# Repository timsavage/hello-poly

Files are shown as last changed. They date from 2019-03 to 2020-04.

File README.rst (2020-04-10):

############################################
Hello Poly - Polyphonic MIDI to CV interface
############################################

Polyphonic MIDI to CV module for modular synths, hardware designed for Eurorack systems.

Features:

- 6x 12bit DACs with a range of 0-~8.192V (assignable as either Note or Control outputs)
- 4x Gate outputs
- Configurable CV range 1V/Octave or 1.2V/Octave (providing a 100mV/step)
- Fully assignable routing of MIDI messages by channel
- Assignable Pitchbend and Channel Aftertouch
- Multiple Polyphony modes
- Support for multiple programs (controlled via program change events)
- Configuration via MIDI
- Gate controlled LFO.
- Firmware is hardware agnostic, could be compiled for other targets.

Hardware
========

- Designed around an STM32F411 32bit ARM MCU
- MSP4822 12bit DACs
- 128x64 SSD1306 OLED display

Software
========

Software currently using Arduino, however, I am migrating to using CMSIS and the STM32 HAL 
using the STM32CubeIDE mainly for the debugging support!

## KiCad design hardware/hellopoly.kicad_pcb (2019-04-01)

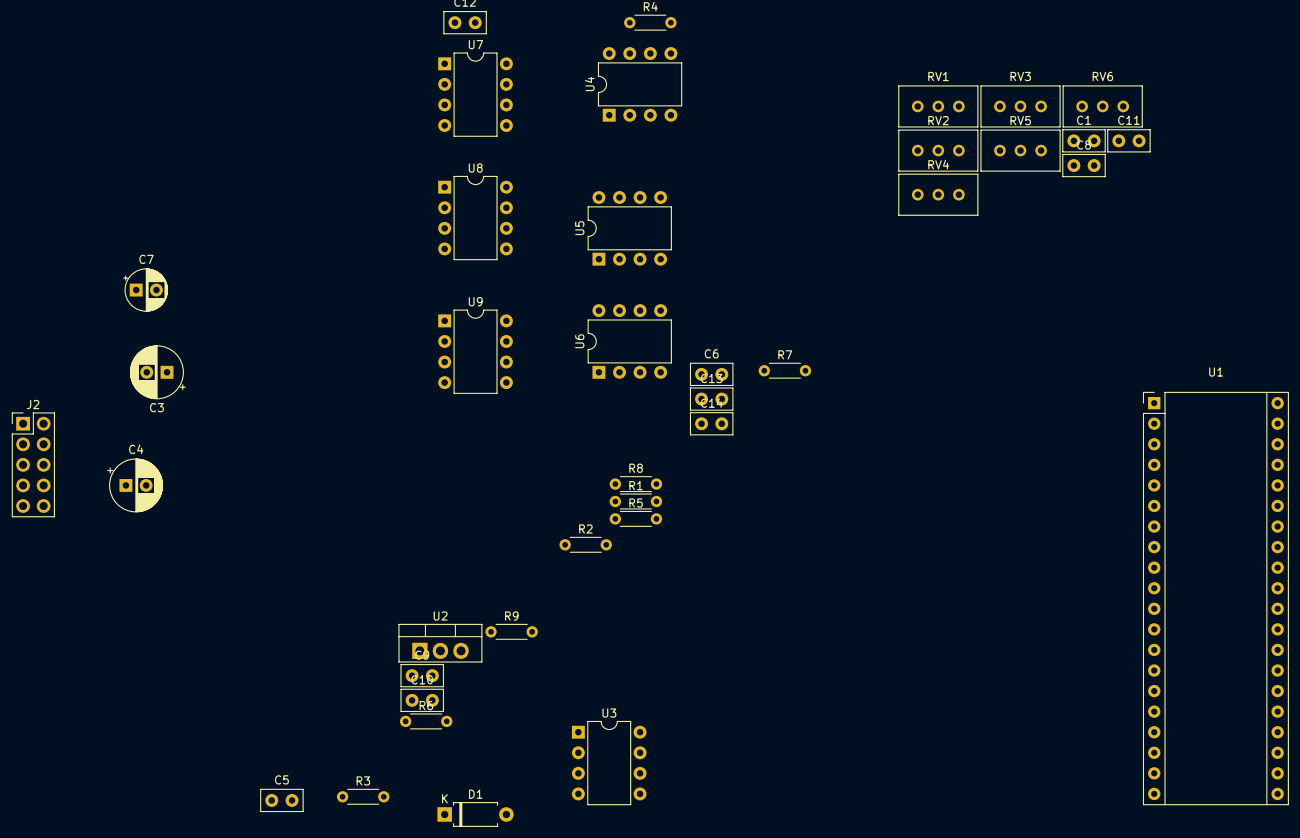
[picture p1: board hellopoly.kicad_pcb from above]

Board: 2 copper layers, 39 parts (0 on the bottom side), 38 nets, no tracks yet.

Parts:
C1, C5, C6, C8, C9, C10, C11, C12, C13, C14: 0.1uF; C_Disc_D5.0mm_W2.5mm_P2.50mm
C3, C4: 47u; CP_Radial_D6.3mm_P2.50mm
C7: 47uF; CP_Radial_D5.0mm_P2.50mm
D1: 1N4148; D_A-405_P7.62mm_Horizontal
J2: Power BUS; PinHeader_2x05_P2.54mm_Vertical
R1: 220R; R_Axial_DIN0204_L3.6mm_D1.6mm_P5.08mm_Horizontal
R2, R4, R5, R6, R7, R8, R9: 10K; R_Axial_DIN0204_L3.6mm_D1.6mm_P5.08mm_Horizontal
R3: 470K; R_Axial_DIN0204_L3.6mm_D1.6mm_P5.08mm_Horizontal
RV1, RV2, RV3, RV4, RV5, RV6: 10K; Potentiometer_Bourns_3296W_Vertical
U1: Bluepill; Maple_Mini
U2: L7805; TO-220-3_Vertical
U3: 6N138; DIP-8_W7.62mm
U4, U5, U6: TL072; DIP-8_W7.62mm
U7, U8, U9: MCP4822; DIP-8_W7.62mm

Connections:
+5V: C7.1, C8.1, C11.1, C12.1, R3.1, U1.38, U2.3, U3.8, U7.1, U8.1, U9.1
+12V: C1.1, C3.1, C5.1, C9.1, C13.1, U2.1, U4.8, U5.8, U6.8
-12V: C4.2, C6.2, C10.2, C14.2, U4.4, U5.4, U6.4
DAC1_CV: R4.1, U4.7
DAC2_CV: R5.1, U4.1
DAC3_CV: R6.1, U5.7
DAC4_CV: R7.1, U5.1
DAC5_CV: R8.1, U6.7
DAC6_CV: R9.1, U6.1
DACA_CS: U1.7, U7.2
DACB_CS: U1.8, U8.2
DACC_CS: U1.9, U9.2
GND: C1.2, C7.2, C8.2, C11.2, C12.2, J2.4, J2.6, J2.8, RV1.2, RV1.3, RV2.2, RV2.3, RV3.2, RV3.3, RV4.2, RV4.3, RV5.2, RV5.3, RV6.2, RV6.3, U1.19, U1.20, U1.39, U2.2, U7.5, U7.7, U8.5, U8.7, U9.5, U9.7
MIDI_RX: R3.2, U1.16, U3.6
unnamed: C3.2, C4.1, J2.3, J2.5, J2.7
unnamed: C5.2, C6.1
unnamed: C9.2, C10.1
unnamed: C13.2, C14.1
unnamed: D1.1, R1.1, U3.2
unnamed: D1.2, U3.3
unnamed: J2.9, J2.10
unnamed: J2.1, J2.2
unnamed: R2.1, U3.7
unnamed: R2.2, U3.5
unnamed: R4.2, RV1.1, U4.6
unnamed: R5.2, RV2.1, U4.2
unnamed: R6.2, RV3.1, U5.6
unnamed: R7.2, RV4.1, U5.2
unnamed: R8.2, RV5.1, U6.6
unnamed: R9.2, RV6.1, U6.2
unnamed: U4.3, U7.6
unnamed: U4.5, U7.8
unnamed: U5.3, U8.6
unnamed: U5.5, U8.8
unnamed: U6.3, U9.6
unnamed: U6.5, U9.8
SPI1_MOSI: U1.12, U7.4, U8.4, U9.4
SPI1_SCK: U1.10, U7.3, U8.3, U9.3

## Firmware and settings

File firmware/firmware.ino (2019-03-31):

#include <Arduino.h>
#include <Wire.h>
#include <SPI.h>

#include "config.h"

#include "devices::dac::DAC.h"
#include "devices::dac::MSP4X2X.hpp"
#include "devices::gate::Gate.h"
#include "devices::midi::Serial.h"
#include "devices::display::SSD1306.h"

#include "core::Control.h"
#include "core::Key.h"

#include "core::polyphony::Polyphony.h"

#include "core::Router.h"

#include "core::ui::View.h"
#include "core::ui::HomeView.hpp"

#define ARRAY_SIZE(x) (sizeof(x) / sizeof(x[0]))


//-- Define devices ------------------------------------------------

devices::dac::MSP4X22 dac0(PA1, MSP4X22_DAC_A);
devices::dac::MSP4X22 dac1(PA1, MSP4X22_DAC_B);
// devices::dac::MSP4X22 dac2(PA4, MSP4X22_DAC_A);
// devices::dac::MSP4X22 dac3(PA4, MSP4X22_DAC_B);
// devices::dac::MSP4X22 dac4(PA5, MSP4X22_DAC_A);
// devices::dac::MSP4X22 dac5(PA5, MSP4X22_DAC_B);
// devices::dac::MockDAC dac0;
// devices::dac::MockDAC dac1;
devices::dac::MockDAC dac2;
devices::dac::MockDAC dac3;
devices::dac::MockDAC dac4;
devices::dac::MockDAC dac5;
devices::dac::DAC *dacList[] = {&dac0, &dac1, &dac2, &dac3, &dac4, &dac5};

devices::gate::Gate gate0(PB12);
devices::gate::Gate gate1(PB13);
devices::gate::Gate gate2(PB14);
devices::gate::Gate gate3(PB15);
devices::gate::Gate *gateList[] = {&gate0, &gate1, &gate2, &gate3};

devices::midi::SerialMIDI midi(&Serial3);
devices::display::SSD1306 display;


//-- Controls ------------------------------------------------------

core::Key key0(&dac0, &gate0);
core::Key key1(&dac1, &gate1);
core::Key key2(&dac2, &gate2);
core::Key key3(&dac3, &gate3);

core::Key *keyList[] = {&key0, &key1, &key2, &key3};

core::ui::View *currentView = NULL;


//-- Initialisation code -------------------------------------------

void 
setupDevices(void)
{
    Wire.begin();
    SPI.begin();

    // Initialise DACs
    for (size_t i = 0; i < ARRAY_SIZE(dacList); i++) {
        dacList[i]->begin();
    }

    // Initialise gates
    for (size_t i = 0; i < ARRAY_SIZE(gateList); i++) {
        gateList[i]->begin();
        gateList[i]->reset();
    }

    midi.begin();
    core::Router.begin(&midi);

    // Delay Initialisation so device can stablise after power is applied.
    delay(500);
    display.begin();
    display.display();
    display.setTextSize(1);
    display.setTextColor(WHITE);
}


//-- Message routing -----------------------------------------------

void
setupProgram(void)
{
    core::Router.empty();
    core::Router.add(0, core::polyphony::ModeOrderedLimit, &keyList[0], 4);
}

void
onControlChange(uint8_t channel, uint8_t control, uint8_t value)
{
    static core::polyphony::PolyphonyMode currentMode;

    if (control == 0x4b) {
        core::polyphony::PolyphonyMode mode = (core::polyphony::PolyphonyMode)((value >> 2) % 8);
        if (mode != currentMode) {
            currentMode = mode;

            core::Router.empty();
            core::Router.add(0, mode, &keyList[0], 4);

            Serial1.print("Activate mode: "); Serial1.print(mode); Serial1.print(" - ");
            core::Route *route = core::Router.getRoute(0);
            Serial1.println(route->mode == NULL);
            Serial1.println(route->mode->name());
            String fmt("M: ");
            fmt += route->mode->name();
        }
    } else {
        Serial1.print("Channel: "); Serial1.print(channel);
        Serial1.print("; Control: "); Serial1.print(control, HEX); 
        Serial1.print("; Value: "); Serial1.println(value);  
    }
}

void
onProgramChange(uint8_t channel, uint8_t program)
{
    Serial1.print("Channel: "); Serial1.print(channel);
    Serial1.print("; Program: "); Serial1.println(program);

    display.setCursor(0, 0);
    display.clearDisplay();
    display.print("Program: "); display.print(program); 
    display.display();
}

void 
setup(void) 
{
    // Set up the built-in LED pin as an output:
    pinMode(PC13, OUTPUT);

    Serial1.begin(115200);
    Serial1.print("Hello Polly - Savage.Company - v0.1\n");
    
    setupDevices();
    setupProgram();

    midi.controlChangeCallback(&onControlChange);
    midi.programChangeCallback(&onProgramChange);

    currentView = new core::ui::HomeView();
}

void 
loop(void) 
{
    midi.loop();

    if (currentView->renderRequired()) {
        currentView->render(&display);
    }
}

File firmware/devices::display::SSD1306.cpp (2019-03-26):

/*********************************************************************
This is a library for our Monochrome OLEDs based on SSD1306 drivers

  Pick one up today in the adafruit shop!
  ------> http://www.adafruit.com/category/63_98

These displays use SPI to communicate, 4 or 5 pins are required to
interface

Adafruit invests time and resources providing this open source code,
please support Adafruit and open-source hardware by purchasing
products from Adafruit!

Written by Limor Fried/Ladyada  for Adafruit Industries.
BSD license, check license.txt for more information
All text above, and the splash screen below must be included in any redistribution
*********************************************************************/

#include <stdlib.h>
#include <Wire.h>

#include "devices::display::SSD1306.h"

using namespace devices::display;


// the memory buffer for the LCD

static uint8_t buffer[SSD1306_LCDHEIGHT * SSD1306_LCDWIDTH / 8] = {
    0x00, 0x00, 0x00, 0x00, 0x00, 0x00, 0x00, 0x00, 0x00, 0x00, 0x00, 0x00, 0x00, 0x00, 0x00, 0x00,
    0x00, 0x00, 0x00, 0x00, 0x00, 0x00, 0x00, 0x00, 0x00, 0x00, 0x00, 0x00, 0x00, 0x00, 0x00, 0x00,
    0x00, 0x00, 0x00, 0x00, 0x00, 0x00, 0x00, 0x00, 0x00, 0x00, 0x00, 0x00, 0x00, 0x00, 0x00, 0x00,
    0x00, 0x00, 0x00, 0x00, 0x00, 0x00, 0x00, 0x00, 0x00, 0x00, 0x00, 0x00, 0x00, 0x00, 0x00, 0x00,
    0x00, 0x00, 0x00, 0x00, 0x00, 0x00, 0x00, 0x00, 0x00, 0x00, 0x00, 0x00, 0x00, 0x00, 0x00, 0x00,
    0x00, 0x00, 0x00, 0x00, 0x00, 0x00, 0x00, 0x00, 0x00, 0x00, 0x00, 0x00, 0x00, 0x00, 0x00, 0x00,
    0x00, 0x00, 0x00, 0x00, 0x00, 0x00, 0x00, 0x00, 0x00, 0x00, 0x00, 0x00, 0x00, 0x00, 0x00, 0x00,
    0x00, 0x00, 0x00, 0x00, 0x00, 0x00, 0x00, 0x00, 0x00, 0x00, 0x00, 0x00, 0x00, 0x00, 0x00, 0x00,
    0x00, 0x00, 0x00, 0x00, 0x00, 0x00, 0x00, 0x00, 0x00, 0x00, 0x00, 0x00, 0x00, 0x00, 0x00, 0x00,
    0x00, 0x00, 0x00, 0x00, 0x00, 0x00, 0x00, 0x00, 0x00, 0x00, 0x00, 0x00, 0x00, 0x00, 0x00, 0x00,
    0x00, 0x00, 0x00, 0x00, 0x00, 0x00, 0x00, 0x00, 0x00, 0x00, 0x00, 0x00, 0x00, 0x00, 0x00, 0x00,
    0x00, 0x00, 0x00, 0x00, 0x00, 0x00, 0x00, 0x00, 0x00, 0x00, 0x00, 0x00, 0x00, 0x00, 0x00, 0x00,
    0x00, 0x00, 0x00, 0x00, 0x00, 0x00, 0x00, 0x00, 0x00, 0x00, 0x00, 0x00, 0x00, 0x00, 0x00, 0x00,
    0x00, 0x00, 0x00, 0x00, 0x00, 0x00, 0x00, 0x00, 0x00, 0x00, 0x00, 0x00, 0x00, 0x00, 0x00, 0x00,
    0x00, 0x00, 0x00, 0x00, 0x00, 0x00, 0x00, 0x00, 0x00, 0x00, 0x00, 0x00, 0x00, 0x00, 0x00, 0x00,
    0x00, 0x00, 0x00, 0x00, 0x00, 0x00, 0x00, 0x00, 0x00, 0x00, 0x00, 0x00, 0x00, 0x00, 0x00, 0x00,
    0x00, 0x00, 0x00, 0x00, 0x00, 0x00, 0x00, 0x00, 0x00, 0x00, 0x00, 0x00, 0x00, 0x00, 0x00, 0x00,
    0x00, 0x00, 0x00, 0x00, 0x00, 0x00, 0x00, 0x00, 0x00, 0x00, 0x00, 0x00, 0x00, 0x00, 0x00, 0x00,
    0x00, 0x00, 0x00, 0x00, 0x00, 0x00, 0x00, 0x00, 0x00, 0x00, 0x00, 0x00, 0x00, 0x00, 0x00, 0x00,
    0x00, 0x00, 0x00, 0x00, 0x00, 0x00, 0x00, 0x00, 0x00, 0x00, 0x00, 0x00, 0x00, 0x00, 0x00, 0x00,
    0x00, 0x00, 0x00, 0x00, 0x00, 0x00, 0x00, 0x00, 0x00, 0x00, 0x00, 0x00, 0x00, 0x00, 0x00, 0x00,
    0x00, 0x00, 0x00, 0x00, 0x00, 0x00, 0x00, 0x00, 0x00, 0x00, 0x00, 0x00, 0x00, 0x00, 0x00, 0x00,
    0x00, 0x00, 0x00, 0x00, 0x00, 0x00, 0x00, 0x00, 0x00, 0x00, 0x00, 0x00, 0x00, 0x00, 0x00, 0x00,
    0x00, 0x00, 0x00, 0x00, 0x00, 0x00, 0x00, 0x00, 0x00, 0x00, 0x00, 0x00, 0x00, 0x00, 0x00, 0x00,
    0x00, 0x00, 0x00, 0x00, 0x00, 0x00, 0x00, 0x00, 0x00, 0x00, 0x00, 0x00, 0x00, 0x00, 0x00, 0x00,
    0x00, 0x00, 0x00, 0x00, 0x00, 0x00, 0x00, 0x00, 0x00, 0x00, 0x00, 0x00, 0x00, 0x00, 0x00, 0x00,
    0x00, 0x00, 0x00, 0x00, 0x00, 0x00, 0x00, 0x00, 0x00, 0x00, 0x00, 0x00, 0x00, 0x00, 0x00, 0x00,
    0x00, 0x00, 0x00, 0x00, 0x00, 0x00, 0x00, 0x00, 0x00, 0x00, 0x00, 0x00, 0x00, 0x00, 0x00, 0x00,
    0x00, 0x00, 0x00, 0x00, 0x00, 0x00, 0x00, 0x00, 0x00, 0x00, 0x00, 0x00, 0x00, 0x00, 0x00, 0x00,
    0x00, 0x00, 0x00, 0x00, 0x00, 0x00, 0x00, 0x00, 0x00, 0x00, 0x00, 0x00, 0x00, 0x00, 0x00, 0x00,
    0x00, 0x00, 0x00, 0x00, 0x00, 0x00, 0x00, 0x00, 0x00, 0x00, 0x00, 0x00, 0x00, 0x00, 0x00, 0x00,
    0x00, 0x00, 0x00, 0x00, 0x00, 0x00, 0x00, 0x00, 0x00, 0x00, 0x00, 0x00, 0x00, 0x00, 0x00, 0x00,
#if (SSD1306_HEIGHT == 64)
    0x00, 0x00, 0x00, 0x00, 0x00, 0x00, 0x00, 0x00, 0x00, 0x00, 0x00, 0x00, 0x00, 0x00, 0x00, 0x00,
    0x00, 0x00, 0x00, 0x00, 0x00, 0x00, 0x00, 0x00, 0x00, 0x00, 0x00, 0x00, 0x00, 0x00, 0x00, 0x00,
    0x00, 0x00, 0x00, 0x00, 0x00, 0x00, 0x00, 0x00, 0x00, 0x00, 0x00, 0x00, 0x00, 0x00, 0x00, 0x00,
    0x00, 0x00, 0x00, 0x00, 0x00, 0x00, 0x00, 0x00, 0x00, 0x00, 0x00, 0x00, 0x00, 0x00, 0x00, 0x00,
    0x00, 0x00, 0x00, 0x00, 0x00, 0x00, 0x00, 0x00, 0x00, 0x00, 0x00, 0x00, 0x00, 0x00, 0x00, 0x00,
    0x00, 0x00, 0x00, 0x00, 0x00, 0x00, 0x00, 0x00, 0x00, 0x00, 0x00, 0x00, 0x00, 0x00, 0x00, 0x00,
    0x00, 0x00, 0x00, 0x00, 0x00, 0x00, 0x00, 0x00, 0x00, 0x00, 0x00, 0x00, 0x00, 0x00, 0x00, 0x00,
    0x00, 0x00, 0x00, 0x00, 0x00, 0x00, 0x00, 0x00, 0x00, 0x00, 0x00, 0x00, 0x00, 0x00, 0x00, 0x00,
    0x00, 0x00, 0x00, 0x00, 0x00, 0x00, 0x00, 0x00, 0x00, 0x00, 0x00, 0x00, 0x00, 0x00, 0x00, 0x00,
    0x00, 0x00, 0x00, 0x00, 0x00, 0x00, 0x00, 0x00, 0x00, 0x00, 0x00, 0x00, 0x00, 0x00, 0x00, 0x00,
    0x00, 0x00, 0x00, 0x00, 0x00, 0x00, 0x00, 0x00, 0x00, 0x00, 0x00, 0x00, 0x00, 0x00, 0x00, 0x00,
    0x00, 0x00, 0x00, 0x00, 0x00, 0x00, 0x00, 0x00, 0x00, 0x00, 0x00, 0x00, 0x00, 0x00, 0x00, 0x00,
    0x00, 0x00, 0x00, 0x00, 0x00, 0x00, 0x00, 0x00, 0x00, 0x00, 0x00, 0x00, 0x00, 0x00, 0x00, 0x00,
    0x00, 0x00, 0x00, 0x00, 0x00, 0x00, 0x00, 0x00, 0x00, 0x00, 0x00, 0x00, 0x00, 0x00, 0x00, 0x00,
    0x00, 0x00, 0x00, 0x00, 0x00, 0x00, 0x00, 0x00, 0x00, 0x00, 0x00, 0x00, 0x00, 0x00, 0x00, 0x00,
    0x00, 0x00, 0x00, 0x00, 0x00, 0x00, 0x00, 0x00, 0x00, 0x00, 0x00, 0x00, 0x00, 0x00, 0x00, 0x00,
    0x00, 0x00, 0x00, 0x00, 0x00, 0x00, 0x00, 0x00, 0x00, 0x00, 0x00, 0x00, 0x00, 0x00, 0x00, 0x00,
    0x00, 0x00, 0x00, 0x00, 0x00, 0x00, 0x00, 0x00, 0x00, 0x00, 0x00, 0x00, 0x00, 0x00, 0x00, 0x00,
    0x00, 0x00, 0x00, 0x00, 0x00, 0x00, 0x00, 0x00, 0x00, 0x00, 0x00, 0x00, 0x00, 0x00, 0x00, 0x00,
    0x00, 0x00, 0x00, 0x00, 0x00, 0x00, 0x00, 0x00, 0x00, 0x00, 0x00, 0x00, 0x00, 0x00, 0x00, 0x00,
    0x00, 0x00, 0x00, 0x00, 0x00, 0x00, 0x00, 0x00, 0x00, 0x00, 0x00, 0x00, 0x00, 0x00, 0x00, 0x00,
    0x00, 0x00, 0x00, 0x00, 0x00, 0x00, 0x00, 0x00, 0x00, 0x00, 0x00, 0x00, 0x00, 0x00, 0x00, 0x00,
    0x00, 0x00, 0x00, 0x00, 0x00, 0x00, 0x00, 0x00, 0x00, 0x00, 0x00, 0x00, 0x00, 0x00, 0x00, 0x00,
    0x00, 0x00, 0x00, 0x00, 0x00, 0x00, 0x00, 0x00, 0x00, 0x00, 0x00, 0x00, 0x00, 0x00, 0x00, 0x00,
    0x00, 0x00, 0x00, 0x00, 0x00, 0x00, 0x00, 0x00, 0x00, 0x00, 0x00, 0x00, 0x00, 0x00, 0x00, 0x00,
    0x00, 0x00, 0x00, 0x00, 0x00, 0x00, 0x00, 0x00, 0x00, 0x00, 0x00, 0x00, 0x00, 0x00, 0x00, 0x00,
    0x00, 0x00, 0x00, 0x00, 0x00, 0x00, 0x00, 0x00, 0x00, 0x00, 0x00, 0x00, 0x00, 0x00, 0x00, 0x00,
    0x00, 0x00, 0x00, 0x00, 0x00, 0x00, 0x00, 0x00, 0x00, 0x00, 0x00, 0x00, 0x00, 0x00, 0x00, 0x00,
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

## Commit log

2019-03-03 Renamed to just devices.hpp, added MIDI port to comment
2019-03-04 Restructured to move hardware definition away into devices namespace
2019-03-04 Merged hal into devices
2019-03-08 Built out polyphony and setup devices, super basic router.
2019-03-08 Tweaks to message handling to handle short messages better
    [devices::midi::Midi.cpp]
2019-03-09 Store the current note on a key
2019-03-12 Support pitch bend in a key
2019-03-21 Ported Adafruit SSD1306, stripped out SPI Made faster for I2C
2019-03-21 Migrated to using customised display driver
2019-03-26 Rebuilt display driver from modified Adafruit library
2019-03-26 Directly use SSD1306 driver
2019-03-31 Initial KiCad files
    [hellopoly.sch]
2019-03-31 Swapped in 128x64 display
    [devices::display::SSD1306.h]
2019-04-01 Started building layout, added footprint for display
    [hellopoly.kicad_pcb, hellopoly.sch]
